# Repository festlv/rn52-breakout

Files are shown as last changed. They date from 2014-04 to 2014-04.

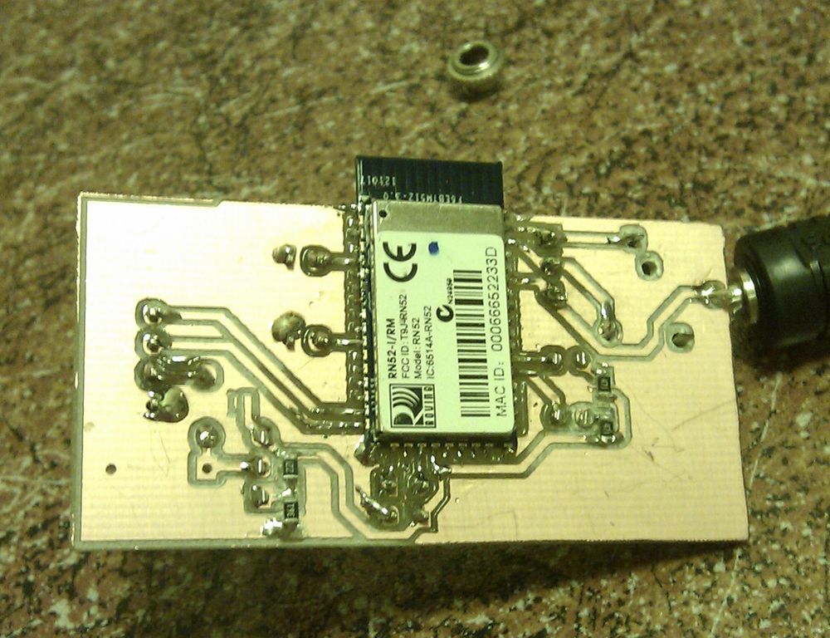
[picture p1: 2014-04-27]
prettypics/soldered.jpg

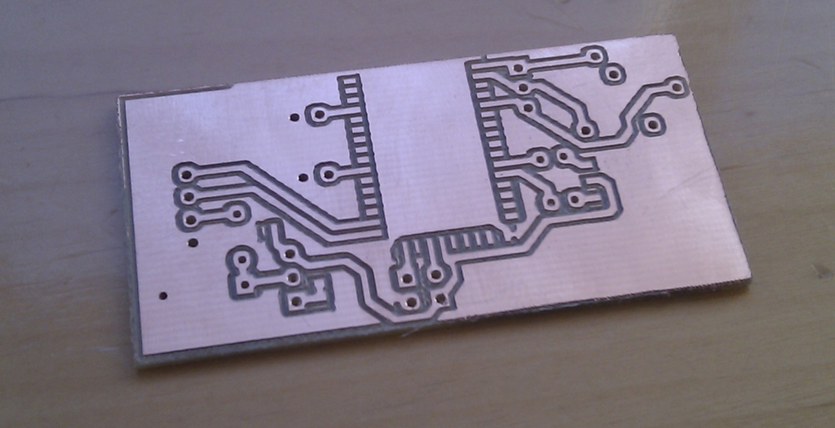
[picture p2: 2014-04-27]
prettypics/milled.jpg

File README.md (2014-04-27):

RN52 breakout board
=======================

KiCad schematics, library symbol and footprints for RN52 Bluetooth module.

The following functionality is broken out:
* UART's RX/TX pins
* GPIO9 (command/data mode selection)
* GPIO7 (UART baud rate selection)
* GPIO4 (factory reset switch)
* PWREN (enable power)
* LED0, LED1
* Audio output, in a really, really dumb way. You should use amplifier with differential input.

Be warned- the PCB was designed for parts I had on hand and home-made production 
process (single layer, fat tracks).

I had wrong footprint for linear regulator at the first try- it's now been
fixed in master.

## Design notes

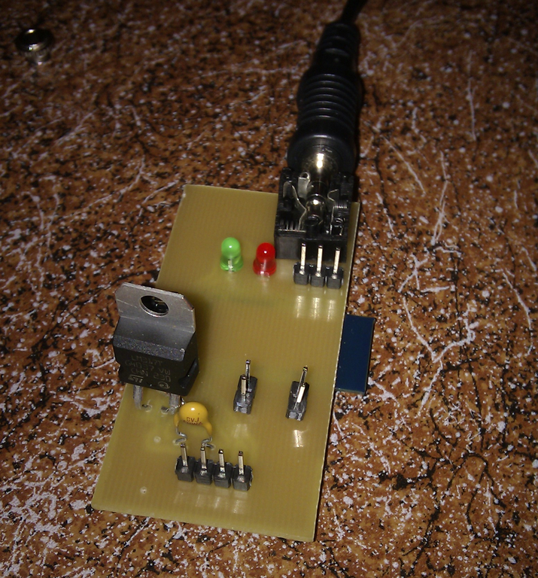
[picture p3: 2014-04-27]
prettypics/populated.jpg

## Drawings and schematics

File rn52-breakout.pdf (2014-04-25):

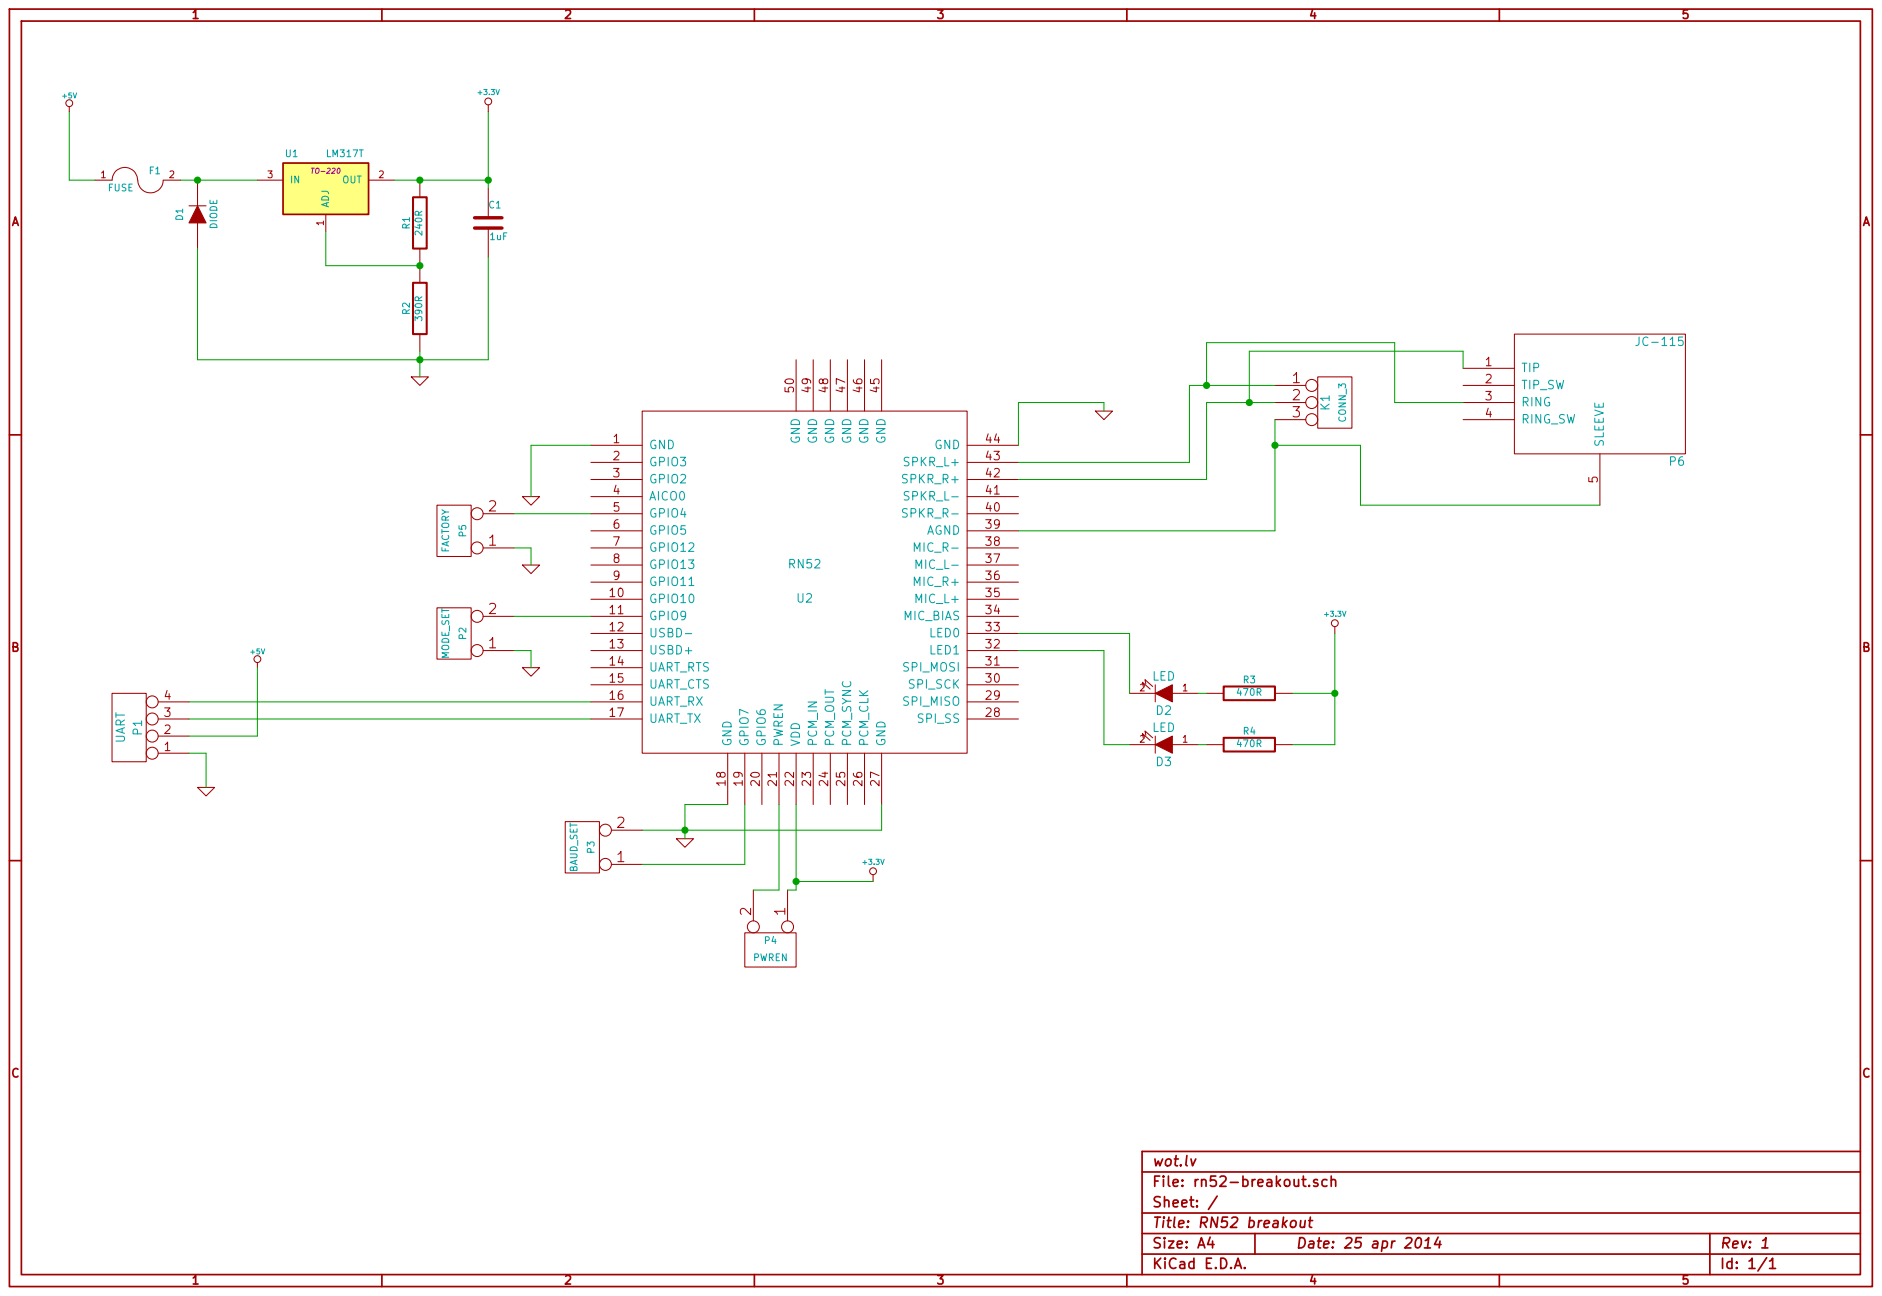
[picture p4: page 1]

Id: 1/1 Title: RN52 breakout File: rn52-breakout.sch Sheet: / wot.lv

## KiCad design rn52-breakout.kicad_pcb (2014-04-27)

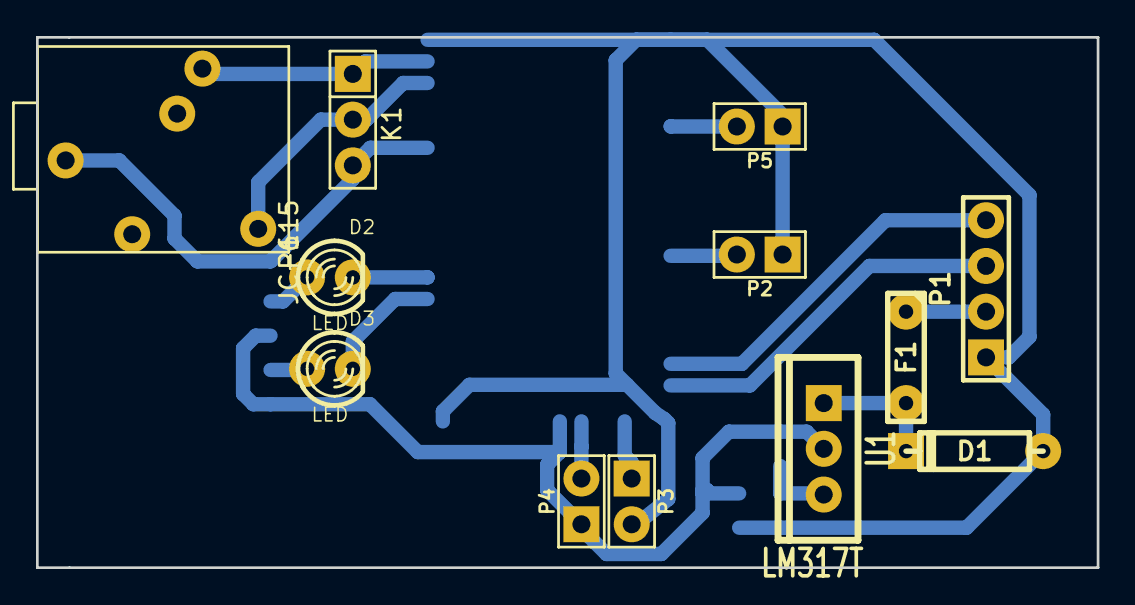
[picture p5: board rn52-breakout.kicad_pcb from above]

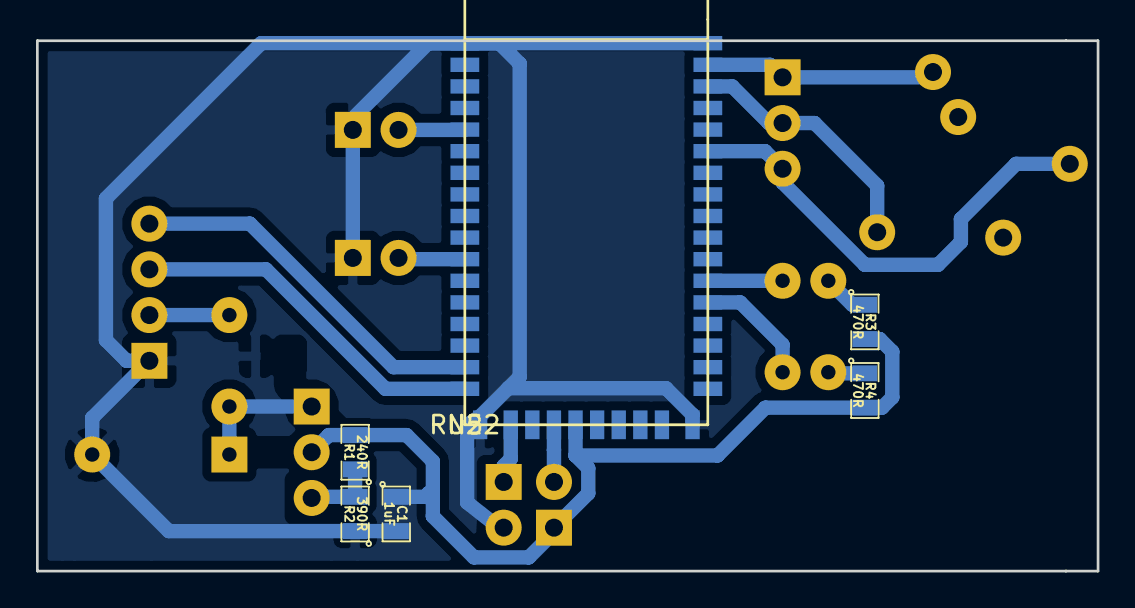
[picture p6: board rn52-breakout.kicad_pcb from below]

Board: 2 copper layers, 58.9 x 29.5 mm, 18 parts (6 on the bottom side), 18 nets.

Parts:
C1: 1uF; SM0805
D1: DIODE; D3
D2, D3: LED; LED-3MM
F1: FUSE; C2
K1: CONN_3; PIN_ARRAY_3X1
P1: UART; PIN_ARRAY_4x1
P2: MODE_SET; PIN_ARRAY_2X1
P3: BAUD_SET; PIN_ARRAY_2X1
P4: PWREN; PIN_ARRAY_2X1
P5: FACTORY; PIN_ARRAY_2X1
P6: JC-115
R1: 240R; SM0805
R2: 390R; SM0805
R3, R4: 470R; SM0805
U1: LM317T; TO220_VERT
U2: RN52

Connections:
+3.3V: C1.1, P4.1, R1.2, R3.2, R4.2, U1.2, U2.22
+5V: F1.1, P1.2
GND: C1.2, D1.1, P1.1, P2.1, P3.2, P5.1, R2.1, U2.1, U2.18, U2.27, U2.44
unnamed: P2.2, U2.11
unnamed: P3.1, U2.19
unnamed: R1.1, R2.2, U1.1
unnamed: D1.2, F1.2, U1.3
unnamed: K1.3, P6.5, U2.39
unnamed: K1.2, P6.1, U2.42
unnamed: K1.1, P6.3, U2.43
unnamed: D2.2, U2.33
unnamed: D3.2, U2.32
unnamed: D3.1, R4.1
unnamed: P5.2, U2.5
unnamed: P1.4, U2.16
unnamed: P4.2, U2.21
unnamed: D2.1, R3.1
unnamed: P1.3, U2.17

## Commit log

2014-04-24 Pre-production version, still need a footprint for audio connector
    [rn52-breakout.kicad_pcb, rn52-breakout.sch]
2014-04-24 Added PDF version of schematics
    [rn52-breakout.sch]
2014-04-25 Added 3.5mm jack connector
    [rn52-breakout.kicad_pcb, rn52-breakout.sch]
2014-04-25 Updated schematic in PDF format
2014-04-27 Fixed incorrect pinout for lin. regul., added some vanity pictures
    [rn52-breakout.kicad_pcb]
